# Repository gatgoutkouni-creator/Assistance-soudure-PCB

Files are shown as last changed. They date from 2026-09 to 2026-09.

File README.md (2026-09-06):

# Assistance Soudure PCB

**Étude et implémentation d'une solution de soudure semi-automatique de cartes électroniques**

Projet de Fin d'Études (PFE) réalisé par **Gatgout Kouni** et **Wedad Louleid**.

## Présentation

Ce projet consiste à concevoir et réaliser une solution d'assistance à la soudure des cartes électroniques (PCB). L'objectif est de faciliter les opérations de soudure en améliorant le positionnement de l'outil et en réduisant les interventions manuelles de l'opérateur.

La solution développée permet d'exploiter les données issues des fichiers Gerber afin d'identifier les positions nécessaires aux opérations de soudure. Ces données sont ensuite traitées et utilisées pour générer les commandes permettant de piloter la machine.

Le système repose sur une interface web permettant à l'utilisateur d'importer les fichiers et de contrôler les différentes étapes du processus. Un serveur développé en Python avec Flask assure le traitement des données et la communication avec le système de commande.

La partie commande de la machine est basée sur une carte Arduino UNO associée à un CNC Shield et à des drivers DRV8825. Le firmware GRBL permet d'interpréter les commandes G-code et de commander les mouvements des axes X, Y et Z.

Une caméra est également utilisée pour assurer la supervision visuelle du système et faciliter le contrôle des opérations.

## Fonctionnement

Le fonctionnement général du système peut être résumé comme suit :

1. Importation du fichier Gerber à travers le dashboard web.
2. Traitement des données du fichier.
3. Extraction des positions nécessaires à la soudure.
4. Validation des points à traiter.
5. Génération des commandes G-code.
6. Envoi des commandes vers le système de commande.
7. Interprétation des commandes par GRBL.
8. Déplacement des axes X, Y et Z.
9. Réalisation des opérations de soudure aux positions définies.
10. Supervision du processus à travers l'interface web et la caméra.

## Architecture du système

Le système est organisé autour de plusieurs parties complémentaires :

**Interface Web → Serveur Python/Flask → Traitement des données → G-code → GRBL → Arduino UNO → CNC Shield + DRV8825 → Axes X/Y/Z**

La caméra permet également de suivre visuellement le fonctionnement de la machine.

## Technologies utilisées

### Logiciel

- Python
- Flask
- HTML / CSS / JavaScript
- G-code
- GRBL

### Commande

- Arduino UNO
- CNC Shield
- DRV8825
- Moteurs pas à pas

### Données et supervision

- Fichiers Gerber
- Dashboard web
- Caméra

## Objectifs du projet

Le système a été développé afin de :

- améliorer la précision du positionnement ;
- faciliter les opérations de soudure ;
- réduire les interventions manuelles ;
- améliorer la répétabilité des opérations ;
- permettre une supervision plus simple du processus.

## Résultats

La solution réalisée permet de traiter les données nécessaires aux opérations de soudure et de commander les déplacements de la machine à partir des positions définies.

Les essais réalisés ont permis de vérifier le fonctionnement de la chaîne de traitement, depuis l'importation des données jusqu'au pilotage des axes de la machine.

## Démonstration vidéo

<video src="videos/demo_gravure_pcb.mp4" controls width="600"></video>

Si la vidéo ne s'affiche pas directement, tu peux la télécharger ou la visionner ici : [videos/demo_gravure_pcb.mp4](videos/demo_gravure_pcb.mp4)

## Aperçu du projet

**De la conception (SolidWorks) à la machine réelle :**

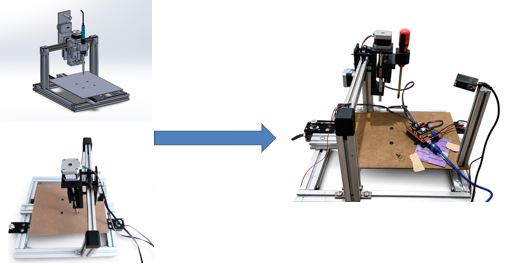
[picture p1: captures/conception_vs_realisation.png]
Conception vs réalisation


**Tableau de bord de contrôle de la machine :**

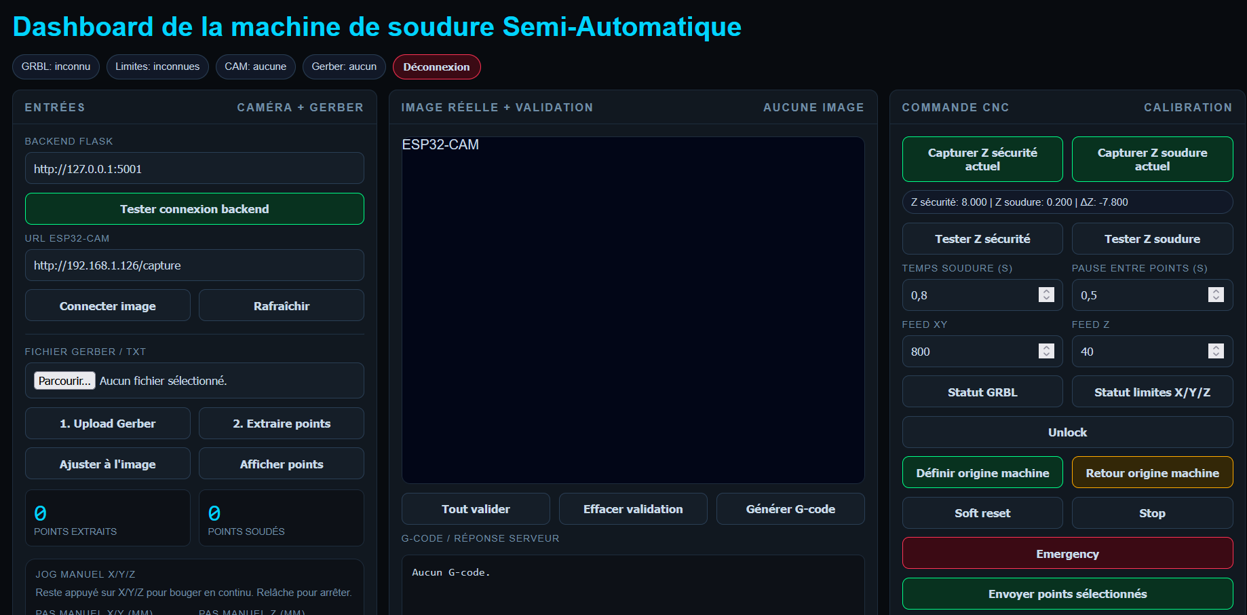
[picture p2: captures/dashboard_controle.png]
Dashboard de contrôle

## NB: identifiant: admin // mot de passe: 1234

## Contexte

Projet de Fin d'Études réalisé au sein de **emkaMED**, Ouardanine, Monastir, Tunisie.

## Auteurs

- **Gatgout Kouni**
- **Wedad Louleid**

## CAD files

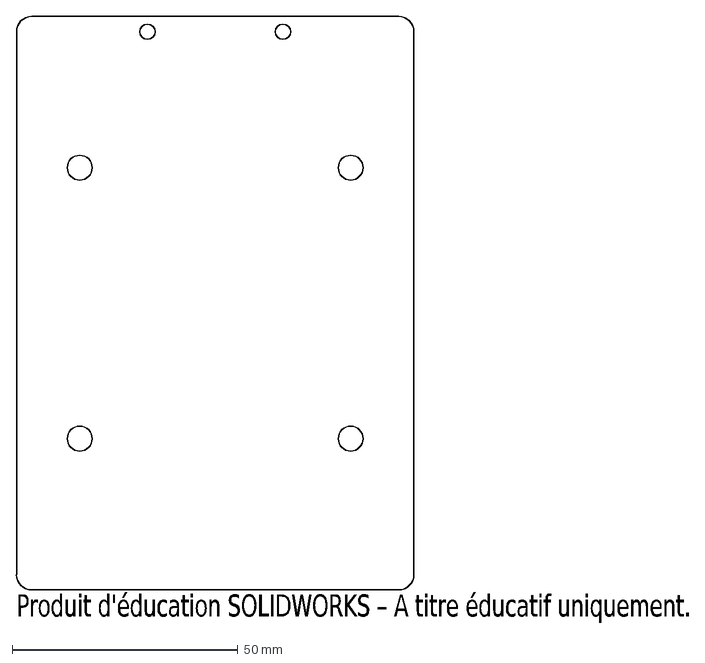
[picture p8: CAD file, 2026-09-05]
PFE kouni/decoupe laser/v-slot X.DXF
Produit d'éducation SOLIDWORKS – A titre éducatif uniquement.

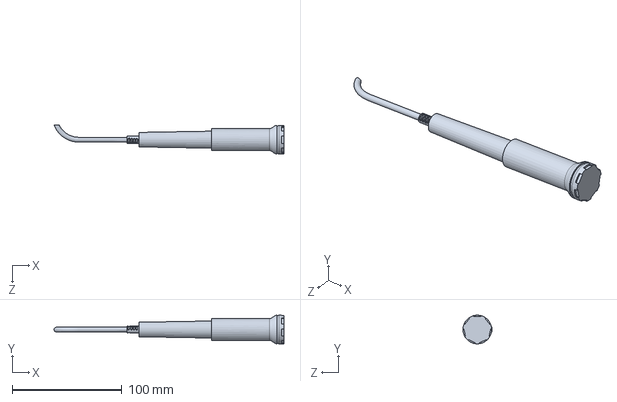
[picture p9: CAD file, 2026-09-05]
PFE kouni/fer/havya makinesi.SLDPRT
209.6 x 26.2 x 26.5 mm

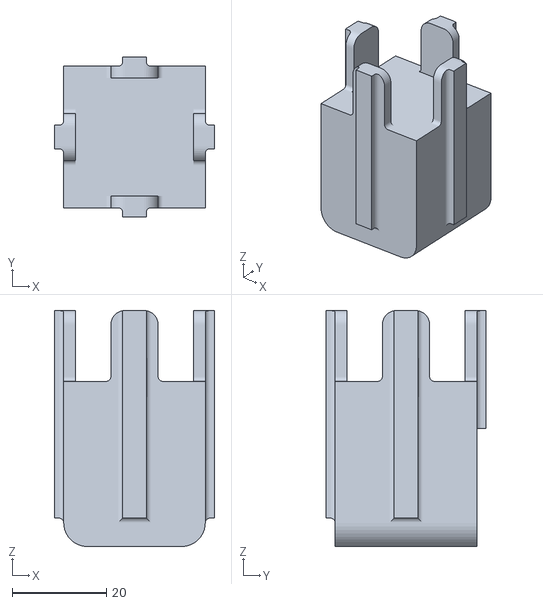
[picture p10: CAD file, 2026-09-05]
PFE kouni/impression/Pièce1.STL
34.0 x 34.0 x 50.0

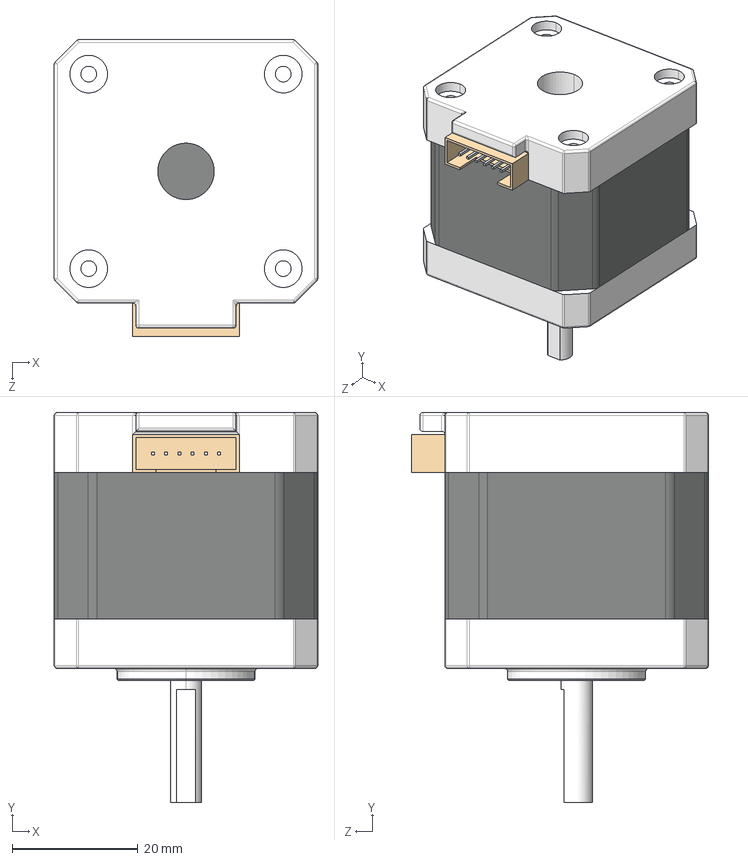
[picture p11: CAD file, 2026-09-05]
PFE kouni/Nema 17 42x40x5/Nima 17 40x42x5mm.STEP
42.0 x 62.1 x 47.3 mm

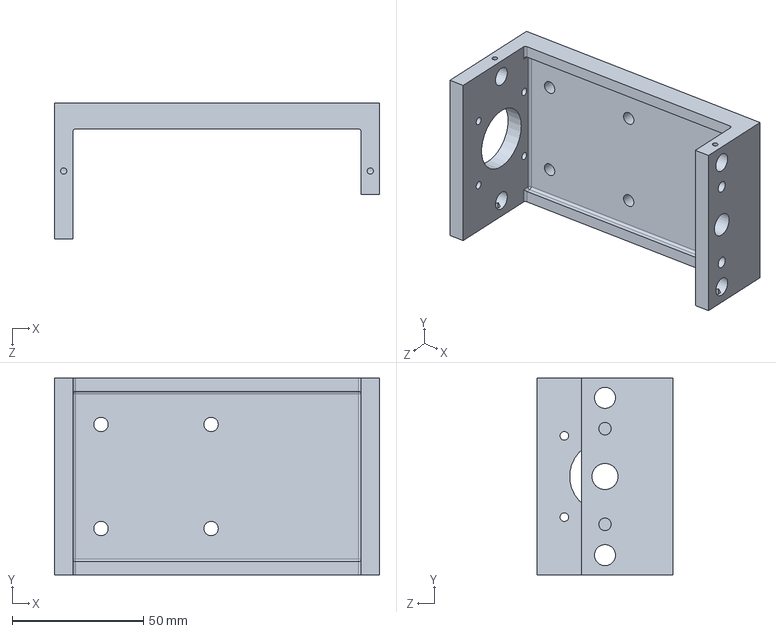
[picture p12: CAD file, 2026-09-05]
PFE kouni/axe Z/bati.SLDPRT
124.0 x 75.0 x 52.0 mm

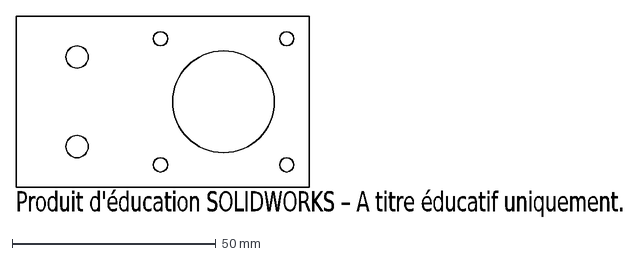
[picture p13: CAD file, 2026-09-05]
PFE kouni/decoupe laser/support moteur x.DXF
Produit d'éducation SOLIDWORKS – A titre éducatif uniquement.

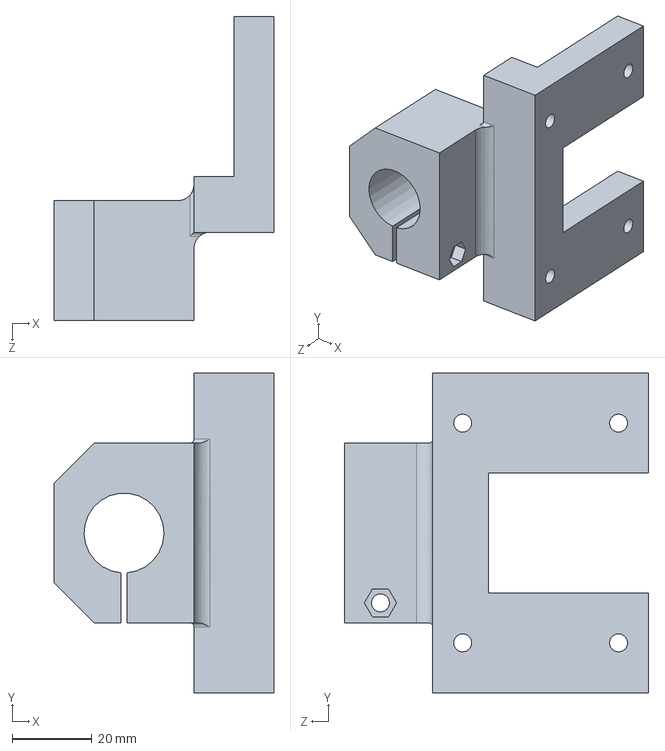
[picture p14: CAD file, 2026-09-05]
PFE kouni/fer/support fer.SLDPRT
55.0 x 80.0 x 76.1 mm

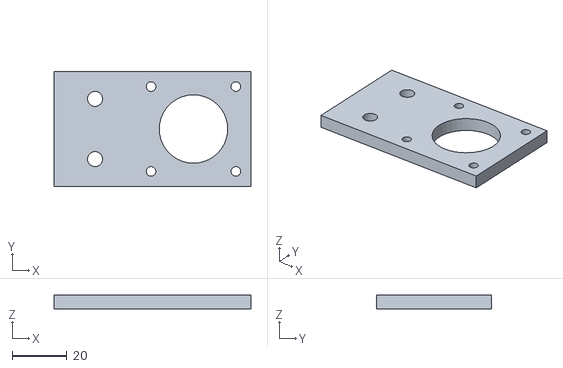
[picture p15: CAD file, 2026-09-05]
PFE kouni/impression/support moteur x.STL
72.0 x 42.0 x 5.00

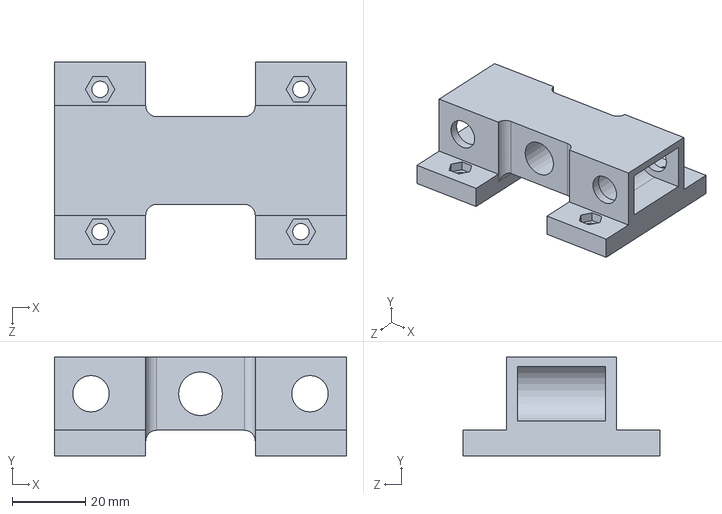
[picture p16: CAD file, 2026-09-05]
PFE kouni/axe Z/glissere.SLDPRT
80.0 x 27.0 x 54.0 mm

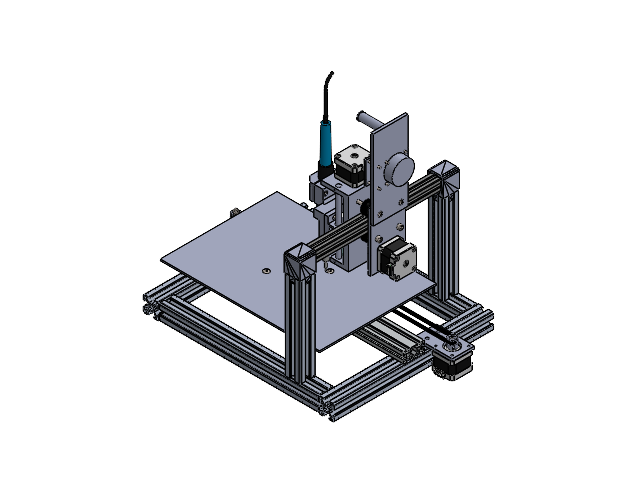
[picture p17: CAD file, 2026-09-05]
PFE kouni/Assem15.SLDASM
3030 ALUMINIUM EXTRUSION x 4
3030 ALUMINIUM EXTRUSION 160mm x 2
2020 ALUMINIUM EXTRUSION
fixation axe x x 2
table
Aluminum Profile 2040
42SHD0034-20B x 3
plaque v slot 2
GT2 x 6mm Pully 5mm Bore x 2
Solid V-Wheel.stp x 9
Ball Bearing 625 2RS 5x16x5.stp x 18
1mm 5mm shim.stp x 9
bati
vis
cphg19-5-8_01
guidage z x 2
roulement lineaire x 2
glissere
palier
socket head cap screw_iso x 16
hex flange nut gradea_iso x 4
support moteur x
Pièce3
angular contact ball bearing_68_iso x 2
GT2 x 6mm Pully 5mm Bore syncro
hex thin nut chamfered gradeab_iso
hex nut gradec_iso
courroie
obs courroie
v-slot X2
socket countersunk head screw_iso x 4
havya makinesi
fer partie 2
support fer
support etain
pas a pas etain
Pièce5

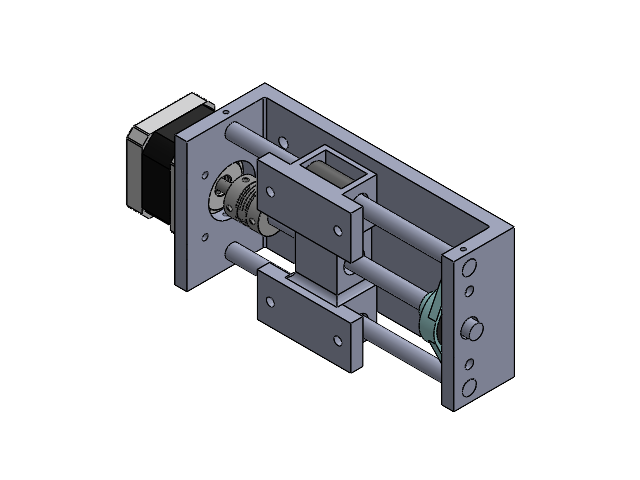
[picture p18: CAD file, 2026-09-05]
PFE kouni/axe Z/Assemblage1.SLDASM
bati
42SHD0034-20B
vis
cphg19-5-8_01
guidage z x 2
roulement lineaire x 2
glissere
palier

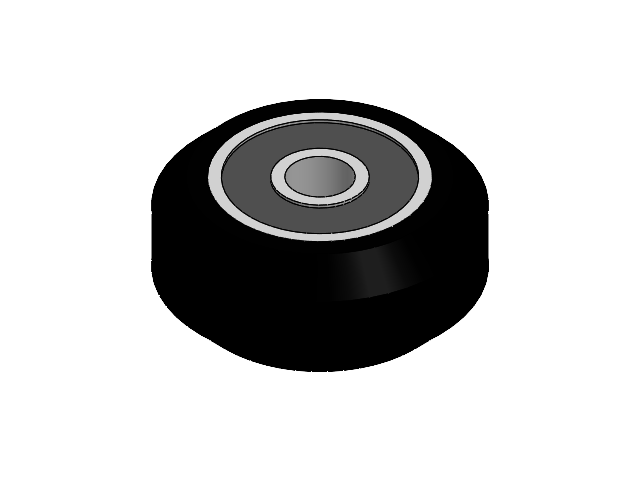
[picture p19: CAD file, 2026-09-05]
PFE kouni/V-Wheel Kit.SLDASM
Solid V-Wheel.stp
Ball Bearing 625 2RS 5x16x5.stp x 2
1mm 5mm shim.stp

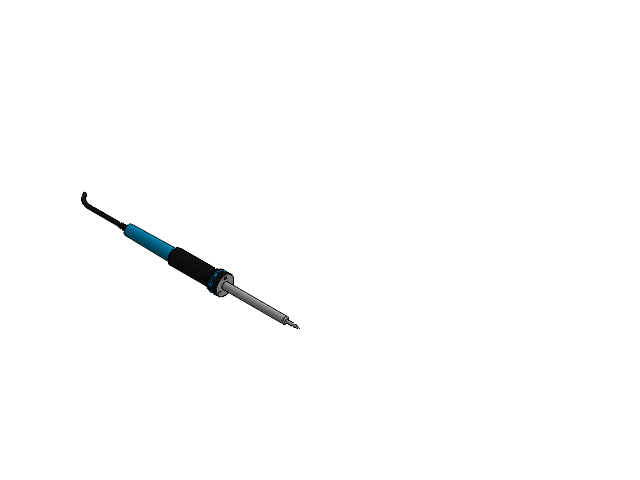
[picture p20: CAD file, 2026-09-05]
PFE kouni/fer/fer.SLDASM
havya makinesi
fer partie 2

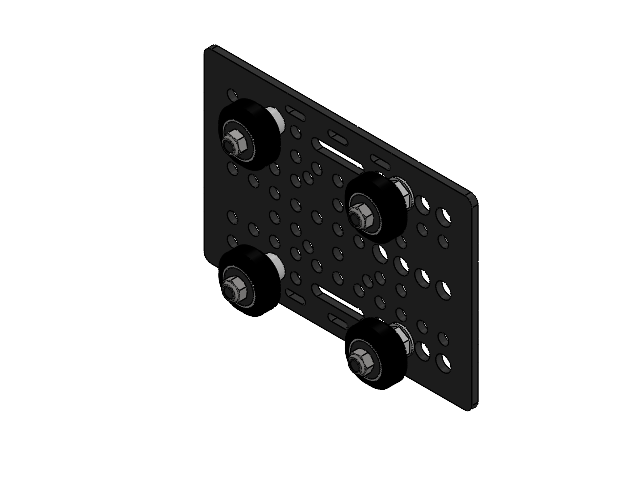
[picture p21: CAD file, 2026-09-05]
PFE kouni/40mm Gantry Set universal.SLDASM
Solid V-Wheel_1.stp x 4
Ball Bearing 625 2RS 5x16x5_1.stp x 8
Eccentric Spacer.stp x 2
1mm 5mm shim_1.stp x 4
6mm Spacer.stp x 2
80mm gantry plate.stp
M5x25 low profile screw.stp x 4
M5 Nylock.stp x 4

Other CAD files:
PFE kouni/V-Wheel Solid Wheel - spacer_1.SLDASM
PFE kouni/V-Wheel Solid Wheel_1.SLDASM
PFE kouni/KP08.SLDASM
PFE kouni/20mm Gantry Set.SLDASM
PFE kouni/1mm 5mm shim_2.SLDPRT
PFE kouni/2020 ALUMINIUM EXTRUSION.SLDPRT
PFE kouni/20mm Gantry Set(2).SLDASM
PFE kouni/20mm gantry plate.SLDPRT
PFE kouni/3030 ALUMINIUM EXTRUSION 160mm.SLDPRT
PFE kouni/3030 ALUMINIUM EXTRUSION.SLDPRT
PFE kouni/42SHD0034-20B.SLDPRT
PFE kouni/6mm Spacer_1.SLDPRT
PFE kouni/Aluminum Profile 2040.SLDPRT
PFE kouni/Ball Bearing 625 2RS 5x16x5_2.SLDPRT
PFE kouni/Eccentric Spacer_1.SLDPRT
PFE kouni/GHLIDH 2.SLDPRT
PFE kouni/GHLIDH.SLDPRT
PFE kouni/GT2 x 6mm Pully 5mm Bore syncro.SLDPRT
PFE kouni/GT2 x 6mm Pully 5mm Bore.SLDPRT
PFE kouni/KOUNIII PIEECE 1 YTB.SLDPRT
PFE kouni/M5 Nylock_1.SLDPRT
PFE kouni/M5x25 low profile screw_1.SLDPRT
PFE kouni/Nema 17 42x40x5/Nima 17 40x42x5mm.SLDPRT
PFE kouni/Pièce1.SLDPRT
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

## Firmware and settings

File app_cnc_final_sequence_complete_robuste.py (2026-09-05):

from flask import Flask, request, jsonify
from flask_cors import CORS
import os, re, time, threading
import serial

app = Flask(__name__)
CORS(app)

# ============================================================
# CONFIGURATION A MODIFIER SELON TON PC
# ============================================================
GRBL_PORT = "COM4"        # Port détecté sur ton PC. Change-le si Windows donne un autre COM.
GRBL_BAUDRATE = 115200
UPLOAD_FOLDER = "uploads"
os.makedirs(UPLOAD_FOLDER, exist_ok=True)

# IMPORTANT : ce backend PEUT modifier $100/$101/$102 uniquement quand tu cliques
# sur "Calculer et appliquer steps/mm". Les valeurs sont sauvegardees dans GRBL.

ser = None
serial_lock = threading.Lock()
stop_event = threading.Event()

current_pos = {"x": 0.0, "y": 0.0, "z": 0.0}
absolute_mode = True

# ============================================================
# REGLAGES DOUX POUR REDUIRE LE BRUIT ET EVITER LES CHOCS
# ============================================================
# Ces valeurs ne changent PAS la calibration $100/$101/$102.
# Elles réduisent seulement la vitesse, l'accélération et le maintien moteur.
SAFE_GRBL_SETTINGS = [
    "$0=10",     # impulsion step standard
    "$1=25",     # relâchement moteur après mouvement, réduit le bruit à l'arrêt
    "$110=1600", # vitesse max X plus rapide
    "$111=1600", # vitesse max Y plus rapide
    "$112=120",  # vitesse max Z prudente
    "$120=120",  # accélération X raisonnable
    "$121=120",  # accélération Y raisonnable
    "$122=10",   # accélération Z douce
]

# Vitesse utilisée pour les boutons Jog et calibration.
JOG_FEED_XY = 1600  # X/Y plus rapides pour jog continu et calibration
JOG_FEED_Z = 80     # Z reste prudent

# Distance longue utilisée uniquement pendant le jog continu.
# Le mouvement s’arrête quand tu relâches le bouton grâce à /jog_stop.
CONTINUOUS_JOG_DISTANCE_XY = 220.0
CONTINUOUS_JOG_DISTANCE_Z = 30.0

# Ton axe Z est inversé mécaniquement : le dashboard garde Z+ / Z-,
# mais le backend inverse le signe envoyé à GRBL pour Z seulement.
INVERT_Z_DIRECTION = True

# Dimensions physiques de ton prototype
# X rail total = 300 mm, mais le chariot/bati prend environ 75 mm => course utile ≈ 225 mm.
# Y plateau = 300 mm. Z à adapter selon ta mécanique.
MAX_TRAVEL_X = 225.0
MAX_TRAVEL_Y = 300.0
MAX_TRAVEL_Z = 100.0


def parse_float_any(value, default=0.0):
    """Accepte 1.5 ou 1,5 depuis le dashboard."""
    try:
        return float(str(value).strip().replace(",", "."))
    except Exception:
        return default


# ============================================================
# OUTILS SERIE / GRBL
# ============================================================
def read_lines(wait_s=0.05):
    global ser
    lines = []
    time.sleep(wait_s)
    if ser is None:
        return lines
    try:
        while ser.in_waiting:
            line = ser.readline().decode(errors="ignore").strip()
            if line:
                lines.append(line)
    except Exception:
        pass
    return lines


def connect_grbl():
    global ser
    if ser is not None and ser.is_open:
        return ser
    ser = serial.Serial(GRBL_PORT, GRBL_BAUDRATE, timeout=0.25)
    time.sleep(1.2)
    read_lines(0.2)
    try:
        ser.reset_input_buffer()
        ser.reset_output_buffer()
    except Exception:
        pass
    return ser


def wait_response(timeout=2.0):
    global ser
    start = time.time()
    raw = []
    while time.time() - start < timeout:
        if stop_event.is_set():
            return "stopped_by_user", raw
        try:
            line = ser.readline().decode(errors="ignore").strip()
        except Exception as e:
            return f"serial_error: {e}", raw
        if not line:
            continue
        raw.append(line)
        low = line.lower()
        if low.startswith("ok"):
            return "ok", raw
        if low.startswith("error") or low.startswith("alarm"):
            return line, raw
    return "timeout", raw


def send_raw(line, timeout=2.0):
    global ser
    line = str(line).strip()
    if not line:
        return {"line": line, "response": "ignored", "raw": []}
    connect_grbl()
    # Nettoyer les anciennes lignes avant d'envoyer une nouvelle commande.
    read_lines(0.02)
    with serial_lock:
        ser.write((line + "\n").encode())
        ser.flush()
    response, raw = wait_response(timeout)
    return {"line": line, "response": response, "raw": raw}


def wait_until_idle(timeout=20.0):
    """Attend que GRBL repasse en Idle après un mouvement.
    Important pour la calibration : on ne calcule pas les steps/mm pendant que l'axe bouge encore.
    """
    start = time.time()
    last = ""
    while time.time() - start < timeout:
        try:
            st = get_status_line(timeout=0.8)
        except Exception:
            st = ""
        if st:
            last = st
            if st.startswith("<Idle"):
                return True, st
            if st.startswith("<Alarm"):
                return False, st
        time.sleep(0.08)
    return False, last or "timeout waiting Idle"


def send_realtime(data: bytes):
    connect_grbl()
    with serial_lock:
        ser.write(data)
        ser.flush()
    time.sleep(0.1)


def send_jog(axis, distance, feed):
    """Déplacement relatif sur UN SEUL axe.
    Version simple et fiable : G21 puis G91 puis G1 axe-distance puis G90.
    Le backend n'envoie JAMAIS X/Y/Z ensemble pour les boutons manuels.
    Si tu demandes Y, la ligne envoyée contient seulement Y.
    """
    axis = str(axis).upper().strip()
    distance = float(distance)
    feed = float(feed)
    if axis not in ["X", "Y", "Z"]:
        raise ValueError("Axe invalide")
    if abs(distance) <= 0:
        raise ValueError("Distance invalide")

    # Inversion logicielle de Z seulement : le dashboard reste logique.
    if axis == "Z" and INVERT_Z_DIRECTION:
        distance = -distance

    results = []
    results.append(send_raw("G21", timeout=2.0))
    results.append(send_raw("G91", timeout=2.0))
    cmd = f"G1 {axis}{distance:.4f} F{feed:.1f}"
    move = send_raw(cmd, timeout=4.0)
    results.append(move)
    idle_ok, idle_status = (False, "")
    if str(move.get("response", "")).lower().startswith("ok"):
        # attendre la fin réelle du déplacement avant de répondre au dashboard
        travel_time = min(60.0, max(8.0, abs(distance) / max(feed, 1.0) * 60.0 + 3.0))
        idle_ok, idle_status = wait_until_idle(timeout=travel_time)
    results.append(send_raw("G90", timeout=2.0))
    return {
        "line": cmd,
        "response": move.get("response", "unknown"),
        "idle_ok": idle_ok,
        "idle_status": idle_status,
        "raw": results,
        "mode": "G21_G91_G1_G90_mono_axis_wait_idle"
    }

def send_continuous_jog(axis, direction):
    """Jog continu : la machine bouge tant que le bouton reste appuyé.
    Le dashboard lance /jog_start au pointerdown et /jog_stop au relâchement.
    GRBL reçoit une seule commande $J mono-axe avec une distance longue, puis 0x85 annule le jog.
    """
    axis = str(axis).upper().strip()
    direction = 1 if float(direction) > 0 else -1
    if axis not in ["X", "Y", "Z"]:
        raise ValueError("Axe invalide")

    feed = JOG_FEED_Z if axis == "Z" else JOG_FEED_XY
    long_dist = CONTINUOUS_JOG_DISTANCE_Z if axis == "Z" else CONTINUOUS_JOG_DISTANCE_XY
    distance = direction * long_dist

    if axis == "Z" and INVERT_Z_DIRECTION:
        distance = -distance

    cmd = f"$J=G91 G21 {axis}{distance:.4f} F{feed:.1f}"
    result = send_raw(cmd, timeout=1.5)
    return {
        "line": cmd,
        "response": result.get("response", "unknown"),
        "raw": [result],
        "mode": "continuous_jog_start_mono_axis"
    }



def map_z_for_grbl(line):
    """Inverse Z dans les commandes de mouvement G0/G1 envoyées à GRBL.
    Le dashboard reste logique : Z positif = direction sécurité voulue.
    On ne modifie pas G92 ni les réglages GRBL.
    """
    if not INVERT_Z_DIRECTION:
        return line
    u = line.upper().strip()
    if not u.startswith(("G0", "G00", "G1", "G01")) or "Z" not in u:
        return line
    def repl(m):
        return "Z" + f"{-float(m.group(1)):.4f}"
    return re.sub(r"Z\s*(-?\d+(?:\.\d+)?)", repl, line, flags=re.IGNORECASE)


def apply_safe_grbl_settings():
    results = []
    for cmd in SAFE_GRBL_SETTINGS:
        results.append(send_raw(cmd, timeout=2.0))
        time.sleep(0.03)
    return results


def soft_reset_grbl():
    global ser
    connect_grbl()
    with serial_lock:
        ser.write(b"\x18")
        ser.flush()
    time.sleep(1.2)
    read_lines(0.5)


def get_status_line(timeout=2.0):
    connect_grbl()
    read_lines(0.02)
    with serial_lock:
        ser.write(b"?")
        ser.flush()
    start = time.time()
    while time.time() - start < timeout:
        line = ser.readline().decode(errors="ignore").strip()
        if line.startswith("<"):
            return line
    return ""


def parse_position(status):
    if not status:
        return None
    for tag in ("WPos:", "MPos:"):
        if tag in status:
            try:
                txt = status.split(tag, 1)[1].split("|", 1)[0].replace(">", "")
                x, y, z = [float(v) for v in txt.split(",")[:3]]
                return {"x": x, "y": y, "z": z}
            except Exception:
                return None
    return None


def parse_pins(status):
    if not status or "Pn:" not in status:
        return []
    txt = status.split("Pn:", 1)[1].split("|", 1)[0].replace(">", "")
    return sorted(list(set(txt.strip())))


def clean_gcode_line(line):
    line = str(line).strip()
    if not line or line.startswith(";"):
        return ""
    line = re.sub(r"\(.*?\)", "", line)
    if ";" in line:
        line = line.split(";", 1)[0]
    return line.strip()


def extract_axis_values(line):
    vals = {}
    for axis, val in re.findall(r"([XYZ])\s*(-?\d+(?:\.\d+)?)", line.upper()):
        vals[axis.lower()] = float(val)
    return vals


def update_position_after_ok(line):
    global absolute_mode, current_pos
    u = line.upper().strip()
    if u.startswith("G90"):
        absolute_mode = True
        return
    if u.startswith("G91"):
        absolute_mode = False
        return
    if u.startswith("G92"):
        vals = extract_axis_values(u)
        for k, v in vals.items():
            current_pos[k] = v
        return
    if u.startswith(("G0", "G00", "G1", "G01")):
        vals = extract_axis_values(u)
        for k, v in vals.items():
            if absolute_mode:
                current_pos[k] = v
            else:
                current_pos[k] += v


def is_motion_or_wait_command(line):
    """Retourne True si la ligne doit être terminée avant de passer à la suivante.
    Pour une machine de soudure, on préfère la fiabilité : chaque déplacement et chaque
    temporisation sont validés avant d'envoyer la suite.
    """
    u = line.upper().strip()
    return u.startswith(("G0", "G00", "G1", "G01", "G4", "G04"))


def estimate_motion_timeout(line, default_timeout=30.0):
    """Estime un timeout suffisant pour ne pas arrêter la séquence au milieu.
    Les anciennes versions avaient un timeout trop court : si une réponse tardait,
    la séquence s'arrêtait et certains points n'étaient pas soudés.
    """
    u = line.upper().strip()
    if u.startswith(("G4", "G04")):
        m = re.search(r"P\s*([-+]?\d+(?:\.\d+)?)", u)
        dwell = float(m.group(1)) if m else 1.0
        return max(10.0, dwell + 8.0)

    vals = extract_axis_values(u)
    feed_match = re.search(r"F\s*([-+]?\d+(?:\.\d+)?)", u)
    feed = float(feed_match.group(1)) if feed_match else JOG_FEED_XY
    feed = max(feed, 1.0)

    # Distance approximative à partir de la position logique connue.
    dist = 0.0
    if vals:
        dx = vals.get('x', current_pos.get('x', 0.0)) - current_pos.get('x', 0.0) if absolute_mode else vals.get('x', 0.0)
        dy = vals.get('y', current_pos.get('y', 0.0)) - current_pos.get('y', 0.0) if absolute_mode else vals.get('y', 0.0)
        dz = vals.get('z', current_pos.get('z', 0.0)) - current_pos.get('z', 0.0) if absolute_mode else vals.get('z', 0.0)
        dist = (dx*dx + dy*dy + dz*dz) ** 0.5
    # temps ≈ distance/feed*60 + marge. Minimum large pour éviter les faux timeouts.
    return min(90.0, max(default_timeout, dist / feed * 60.0 + 8.0))


def send_gcode_lines(lines):
    """Envoie une séquence G-code de soudure de manière robuste.

    Amélioration importante : l'ancienne version envoyait les lignes rapidement et
    s'arrêtait dès qu'un timeout apparaissait. Ici, chaque mouvement G0/G1 et chaque
    attente G4 sont suivis par une attente réelle de l'état Idle. Cela évite que le bec
    saute des points ou que la séquence s'interrompe avant la fin.
    """
    stop_event.clear()
    results = []
    connect_grbl()
    read_lines(0.05)

    executed_points = 0
    current_point_comment = None

    for original in lines:
        if stop_event.is_set():
            results.append({"line": "STOP", "response": "stopped_by_user", "raw": ["Sequence arretee."]})
            break

        original_str = str(original).strip()
        if original_str.startswith("; Point"):
            current_point_comment = original_str
            # On ne l'envoie pas à GRBL, mais on le garde dans les résultats.
            results.append({"line": original_str, "response": "comment", "raw": []})
            continue

        line = clean_gcode_line(original_str)
        if not line:
            continue

        line_to_send = map_z_for_grbl(line)
        timeout = estimate_motion_timeout(line, default_timeout=12.0)
        result = send_raw(line_to_send, timeout=timeout)
        result["original_line"] = line
        if current_point_comment:
            result["point_comment"] = current_point_comment

        resp = str(result.get("response", "")).lower()
        if resp.startswith("ok"):
            update_position_after_ok(line)

            # Pour les commandes critiques, attendre la fin réelle du mouvement.
            if is_motion_or_wait_command(line):
                idle_timeout = estimate_motion_timeout(line, default_timeout=20.0)
                idle_ok, idle_status = wait_until_idle(timeout=idle_timeout)
                result["idle_ok"] = idle_ok
                result["idle_status"] = idle_status
                if not idle_ok:
                    result["response"] = "idle_timeout"
                    results.append(result)
                    break

            # Compter le point après la remontée Z sécurité qui suit le contact soudure.
            if current_point_comment and line.upper().startswith(("G1", "G01")) and "Z" in line.upper():
                try:
                    zval = extract_axis_values(line).get('z', None)
                    if zval is not None and zval >= current_pos.get('z', 0.0):
                        pass
                except Exception:
                    pass
        results.append(result)

        if resp.startswith("error") or resp.startswith("alarm") or resp in ("timeout", "stopped_by_user", "serial_error"):
            break
        time.sleep(0.05)

    return results

# ============================================================
# GERBER SIMPLE PARSER
# ============================================================
def parse_fsla(text):
    # Exemple Proteus : %FSLAX24Y24*%  => 2 entiers + 4 decimales
    m = re.search(r"FSLAX(\d)(\d)Y(\d)(\d)", text)
    if m:
        return int(m.group(2)), int(m.group(4))
    # compatibilite avec quelques variantes
    m = re.search(r"FSLA.?X(\d)(\d)Y(\d)(\d)", text)
    if m:
        return int(m.group(2)), int(m.group(4))
    return 4, 4


def parse_units(text):
    return "inch" if "MOIN" in text else "mm"


def gerber_number(raw, decimals, units):
    raw = str(raw).strip()
    # int("+1500") et int("-1500") sont acceptes par Python
    val = int(raw) / (10 ** decimals)
    if units == "inch":
        val *= 25.4
    return val


def extract_gerber_points(text):
    xdec, ydec = parse_fsla(text)
    units = parse_units(text)
    points, seen = [], set()
    patterns = [re.compile(r"X([+-]?\d+)Y([+-]?\d+)D03\*"), re.compile(r"X([+-]?\d+)Y([+-]?\d+)")]
    for pattern in patterns:
        for xr, yr in pattern.findall(text):
            x = gerber_number(xr, xdec, units)
            y = gerber_number(yr, ydec, units)
            key = (round(x, 4), round(y, 4))
            if key not in seen:
                seen.add(key)
                points.append({"x": x, "y": y})
        if points:
            break
    return points

# ============================================================
# ROUTES API
# ============================================================
@app.route("/")
def home():
    return jsonify({"status": "ok", "message": "Backend CNC actif - origine machine conservee, calibration PCB 2 coins cote dashboard, Z securite haut/bas."})

@app.route("/status")
def status():
    try:
        status_line = get_status_line()
        pos = parse_position(status_line)
        if pos:
            current_pos.update(pos)
        return jsonify({"status": "ok", "grbl_status": status_line, "position": pos or current_pos, "pins": parse_pins(status_line)})
    except Exception as e:
        return jsonify({"status": "error", "message": str(e)}), 500

@app.route("/limit_status")
def limit_status():
    try:
        status_line = get_status_line()
        pins = parse_pins(status_line)
        return jsonify({
            "status": "ok",
            "grbl_status": status_line,
            "pins": pins,
            "x_active": "X" in pins,
            "y_active": "Y" in pins,
            "z_active": "Z" in pins,
        })
    except Exception as e:
        return jsonify({"status": "error", "message": str(e)}), 500

@app.route("/unlock", methods=["POST"])
def unlock():
    try:
        stop_event.clear()
        result = send_raw("$X", timeout=4.0)
        return jsonify({"status": "ok", "message": "Unlock envoye.", "results": [result]})
    except Exception as e:
        return jsonify({"status": "error", "message": str(e)}), 500

@app.route("/set_machine_origin", methods=["POST"])
def set_machine_origin():
    try:
        results = send_gcode_lines(["G21", "G90", "G92 X0 Y0 Z0"])
        current_pos.update({"x": 0.0, "y": 0.0, "z": 0.0})
        return jsonify({"status": "ok", "message": "Position actuelle enregistree comme origine machine X0 Y0 Z0.", "results": results})
    except Exception as e:
        return jsonify({"status": "error", "message": str(e)}), 500

@app.route("/homing", methods=["POST"])
def homing_return_manual_origin():
    try:
        # Mode sans fins de course : retour a l'origine definie par G92.
        # On monte/retourne Z vers 0 puis X/Y vers 0. Definis l'origine machine avec Z en hauteur securisee.
        lines = ["G21", "G90", "G1 Z0.000 F80", "G1 X0.000 Y0.000 F800"]
        results = send_gcode_lines(lines)
        return jsonify({"status": "ok", "message": "Retour origine machine manuelle termine.", "results": results})
    except Exception as e:
        return jsonify({"status": "error", "message": str(e)}), 500

@app.route("/send_gcode_sequence", methods=["POST"])
def send_gcode_sequence():
    try:
        data = request.get_json(silent=True) or {}
        lines = data.get("lines", [])
        if not isinstance(lines, list) or not lines:
            return jsonify({"status": "error", "message": "Sequence vide."}), 400
        results = send_gcode_lines(lines)
        return jsonify({"status": "ok", "count": len(results), "results": results})
    except Exception as e:
        return jsonify({"status": "error", "message": str(e)}), 500

@app.route("/soft_reset", methods=["POST"])
def soft_reset():
    try:
        stop_event.set()
        soft_reset_grbl()
        stop_event.clear()
        return jsonify({"status": "ok", "message": "Soft reset envoye."})
    except Exception as e:
        return jsonify({"status": "error", "message": str(e)}), 500

@app.route("/stop", methods=["POST"])
def stop():
    try:
        stop_event.set()
        send_realtime(b"\x85")  # annule un jog GRBL
        send_realtime(b"!")      # feed hold
        return jsonify({"status": "ok", "message": "STOP / Jog cancel envoyé."})
    except Exception as e:
        return jsonify({"status": "error", "message": str(e)}), 500


@app.route("/jog_start", methods=["POST"])
def jog_start():
    """Démarre un jog continu sur un seul axe. Utilisé quand tu restes appuyé sur X+/X-/Y+/Y-/Z+/Z-."""
    try:
        data = request.get_json(silent=True) or {}
        axis = str(data.get("axis", "X")).upper().strip()
        direction = parse_float_any(data.get("direction", 1), 1.0)
        result = send_continuous_jog(axis, direction)
        return jsonify({"status": "ok", "message": f"Jog continu {axis} démarré. Relâche le bouton pour arrêter.", "results": [result], "command_sent": result.get("line")})
    except Exception as e:
        return jsonify({"status": "error", "message": str(e)}), 500

@app.route("/jog_stop", methods=["POST"])
def jog_stop():
    """Arrête immédiatement le jog continu GRBL."""
    try:
        send_realtime(b"\x85")  # Jog cancel GRBL 1.1
        return jsonify({"status": "ok", "message": "Jog continu arrêté."})
    except Exception as e:
        return jsonify({"status": "error", "message": str(e)}), 500

@app.route("/emergency", methods=["POST"])
def emergency():
    try:
        stop_event.set()
        send_realtime(b"!")
        time.sleep(0.1)
        soft_reset_grbl()
        stop_event.clear()
        return jsonify({"status": "ok", "message": "Emergency + reset envoyes."})
    except Exception as e:
        return jsonify({"status": "error", "message": str(e)}), 500
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

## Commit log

2026-09-05 Premier commit : PFE assistance soudure PCB
    [1mm 5mm shim_2.SLDPRT, 2020 ALUMINIUM EXTRUSION.SLDPRT, 20mm Gantry Set(2).SLDASM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]
2026-09-05 Correction du nom de l'auteur
2026-09-05 Ajout du dashboard de controle
2026-09-05 Ajout de la video de demonstration
2026-09-05 Suppression de l'image gravure, remplacee par la video
